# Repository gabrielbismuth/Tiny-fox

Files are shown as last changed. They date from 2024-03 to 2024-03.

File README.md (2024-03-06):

# Tiny-fox
Descripción del Proyecto Este repositorio contiene los archivos de diseño de una placa de circuito impreso (PCB) basada en el ESP32 Pico D4. La PCB ha sido diseñada con el objetivo de proporcionar una plataforma flexible y de código abierto para proyectos de IoT, desarrollo de productos y prototipado rápido.

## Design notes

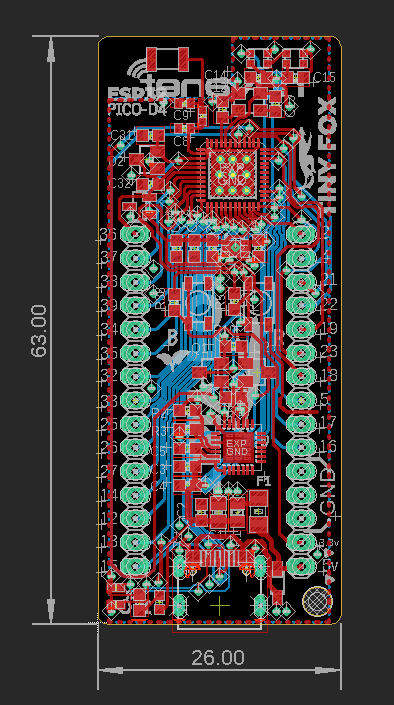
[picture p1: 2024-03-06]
tiny fox.png

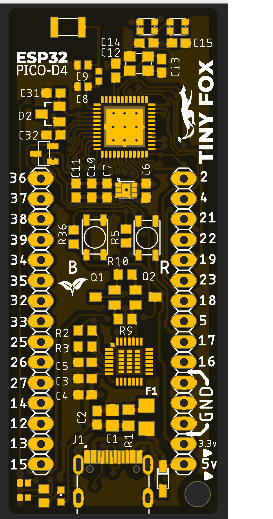
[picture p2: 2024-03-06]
tiny fox render.png

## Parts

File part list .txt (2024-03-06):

Partlist

Exported from tiny fox predatronics.sch at 05/03/2024 07:37 p. m.

EAGLE Version 9.5.2 Copyright (c) 1988-2019 Autodesk, Inc.

Assembly variant: 

Part     Value          Device                 Package            Library                 Sheet

C1       10uf           C-USC0805              C0805              rcl                     1
C2       0.1uf          C-USC0603              C0603              rcl                     1
C3       0.1uf          C-USC0603              C0603              rcl                     1
C4       1uf            C-USC0603              C0603              rcl                     1
C5       1uf            C-USC0603              C0603              rcl                     1
C6       1uf            C-USC0603              C0603              rcl                     1
C7       1uf            C-USC0603              C0603              rcl                     1
C8       1.5pf          C-USC0402              C0402              rcl                     1
C9       1.2pf          C-USC0402              C0402              rcl                     1
C10      0.1uf          C-USC0603              C0603              rcl                     1
C11      1uf            C-USC0603              C0603              rcl                     1
C12      18pf           C-USC0603              C0603              rcl                     1
C13      18pf           C-USC0603              C0603              rcl                     1
C14      0.1uf          C-USC0603              C0603              rcl                     1
C15      0.1uf          C-USC0603              C0603              rcl                     1
C31      0.1uf          C-USC0603              C0603              rcl                     1
C32      680pf          C-USC0603              C0603              rcl                     1
D2       BAS40-04       BAS40-04               SOT23              diode                   1
F1       6V/0.75A       PPTC_THREE-QUARTER-AMP 1206               SparkFun-Fuses          1
IC1      CP2102         CP2102                 MLP28              silabs                  1
J1       TYPE-C-31-M-12 TYPE-C-31-M-12         HRO_TYPE-C-31-M-12 TYPE-C-31-M-12          1
JP1                     PINHD-1X15             1X15               pinhead                 1
JP2                     PINHD-1X15             1X15               pinhead                 1
LED1                    LEDCHIPLED_0603        CHIPLED_0603       adafruit                1
Q1       MUN2211T1      MUN2211T1              SC59-BEC           transistor-npn          1
Q2       MUN2211T1      MUN2211T1              SC59-BEC           transistor-npn          1
R1       FB             R-US_R0805             R0805              audio amplifier example 1
R2       33R            R-US_R0603             R0603              resistor                1
R3       33R            R-US_R0603             R0603              resistor                1
R4       1k             R-US_R0603             R0603              resistor                1
R5       10k            R-US_R0603             R0603              adafruit                1
R6       5.1k           R-US_R0402             R0402              rcl                     1
R7       5.1k           R-US_R0402             R0402              rcl                     1
R9       10k            R-US_R0603             R0603              resistor                1
R10      10k            R-US_R0603             R0603              resistor                1
R36      10k            R-US_R0603             R0603              adafruit                1
U$1      ESP32-PICO-D4  ESP32-PICO-D4          QFN48              esp32-pico-d4           1
U$2      WS2812B-2020   WS2812B-2020           2020               ws2812b-2020            1
U$3      NCP705         NCP705                 WDFN6              NCP705                  1
U$4      6.1nH          INDUCTOR_0402_M        RESC0402_M         Nordic_nRF              1
U$5      CHIP-ANTHENA   CHIP-ANTHENA           ANTHENFOOT         NN01-110                1
U$6      ECX-32         ECX-32                 EXC-32             cristal                 1
U$7      WS2812B-2020   WS2812B-2020           2020               ws2812b-2020            1
U$10     RB160MM-50TF   RB160MM-50TF           SOD-123FL          RB160MM-50TF            1
U$21     TMP23X-Q1      TMP23X-Q1              SOT-23             TMP23x-Q1               1
U$22     XUNPU          XUNPU                  TS-1089S           TS-1089S-02526          1
U$23     XUNPU          XUNPU                  TS-1089S           TS-1089S-02526          1

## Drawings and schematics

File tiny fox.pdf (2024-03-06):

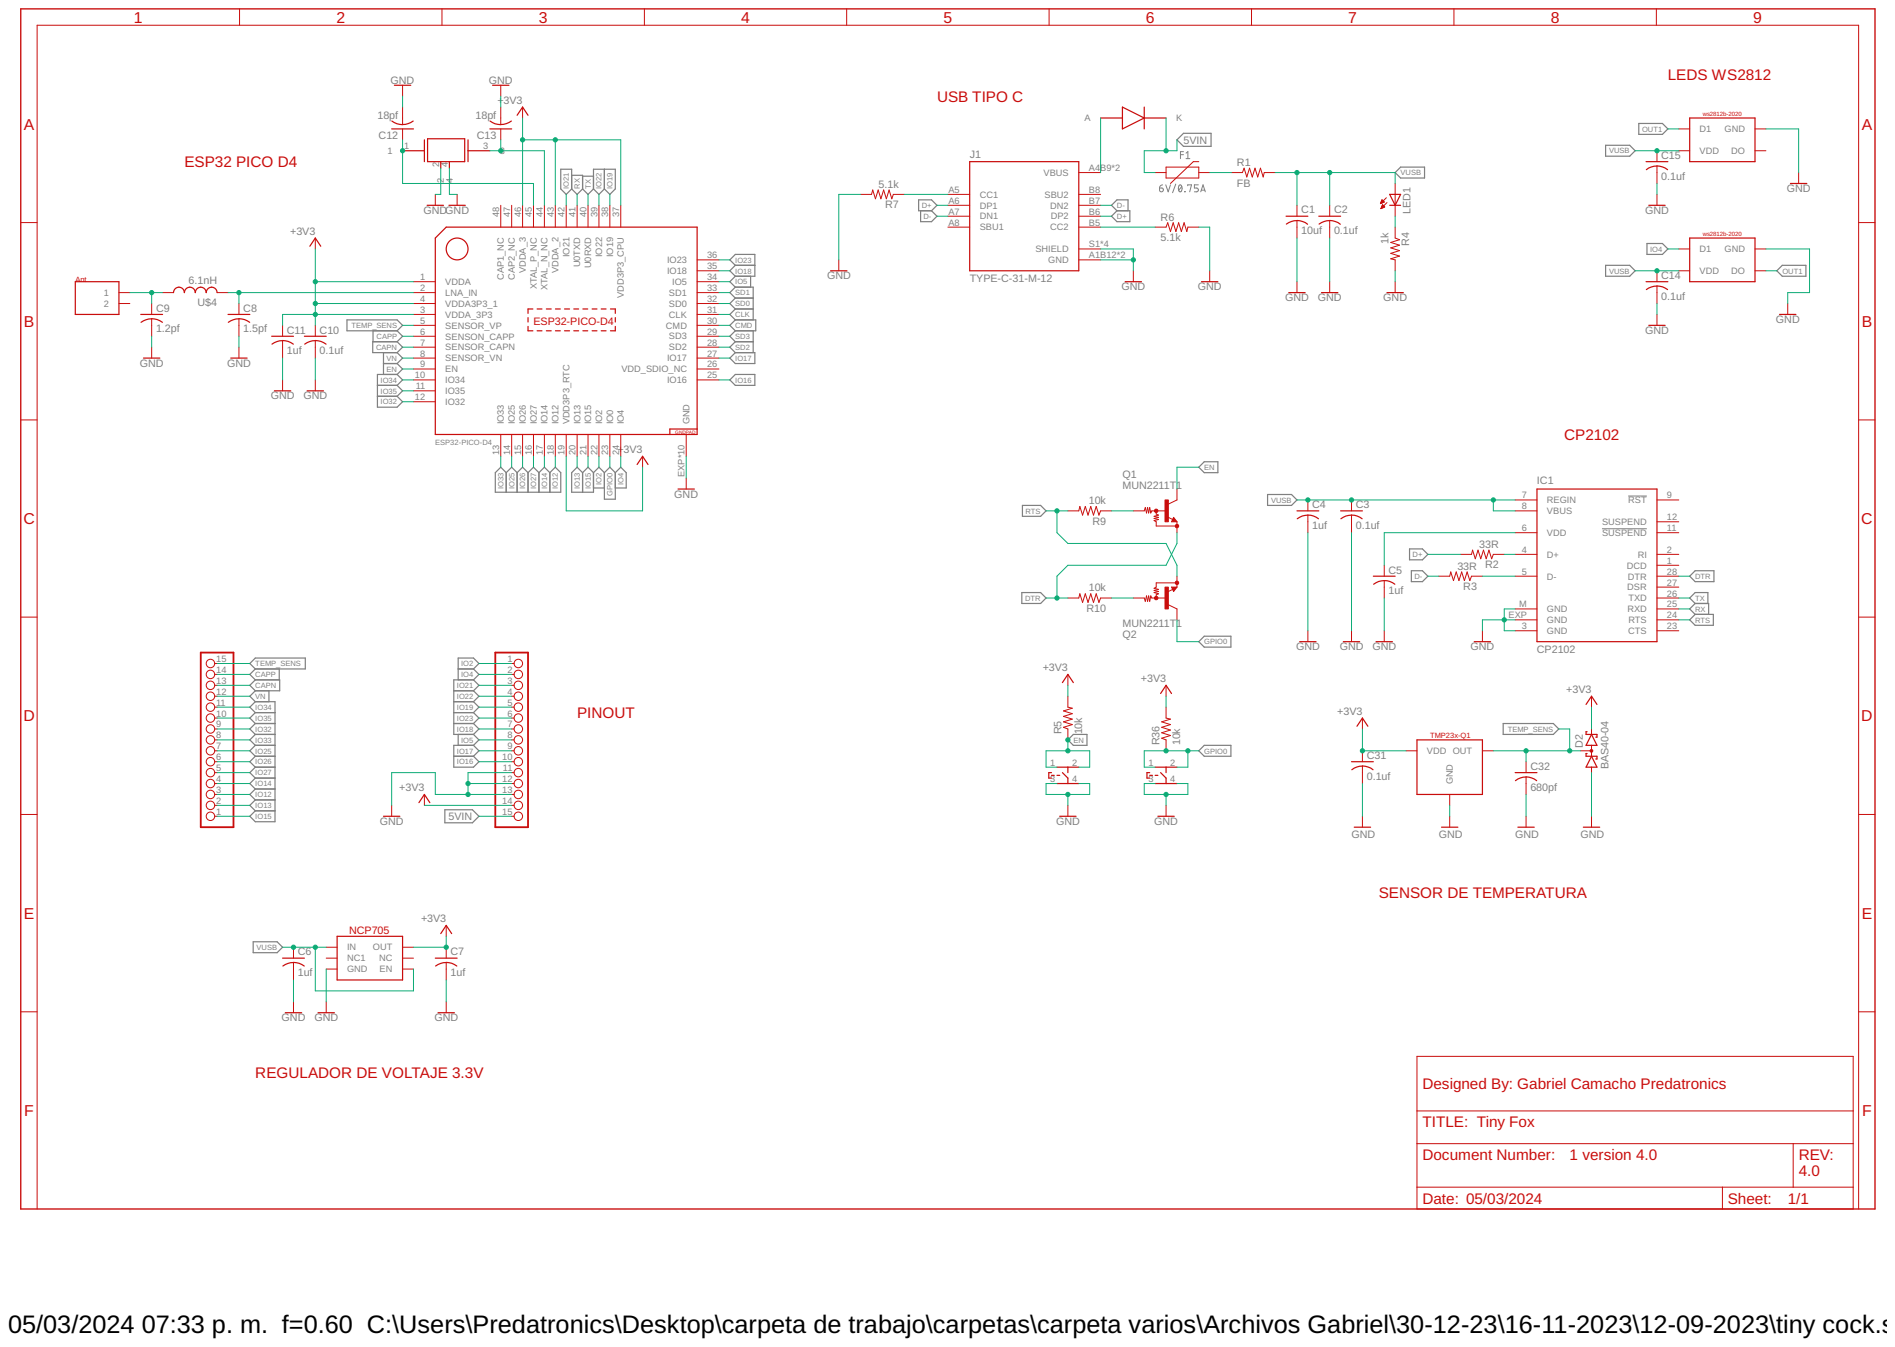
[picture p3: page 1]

Designed By: Gabriel Camacho Predatronics | 4.0

Tiny Fox 05/03/2024 Date: Sheet: 1/1 1 version 4.0 | REV: TITLE: Document Number:

05/03/2024 07:33 p. m. f=0.60 C:\Users\Predatronics\Desktop\carpeta de trabajo\carpetas\carpeta varios\Archivos Gabriel\30-12-23\16-11-2023\12-09-2023\tiny cock.sch (Sheet: 1/1)

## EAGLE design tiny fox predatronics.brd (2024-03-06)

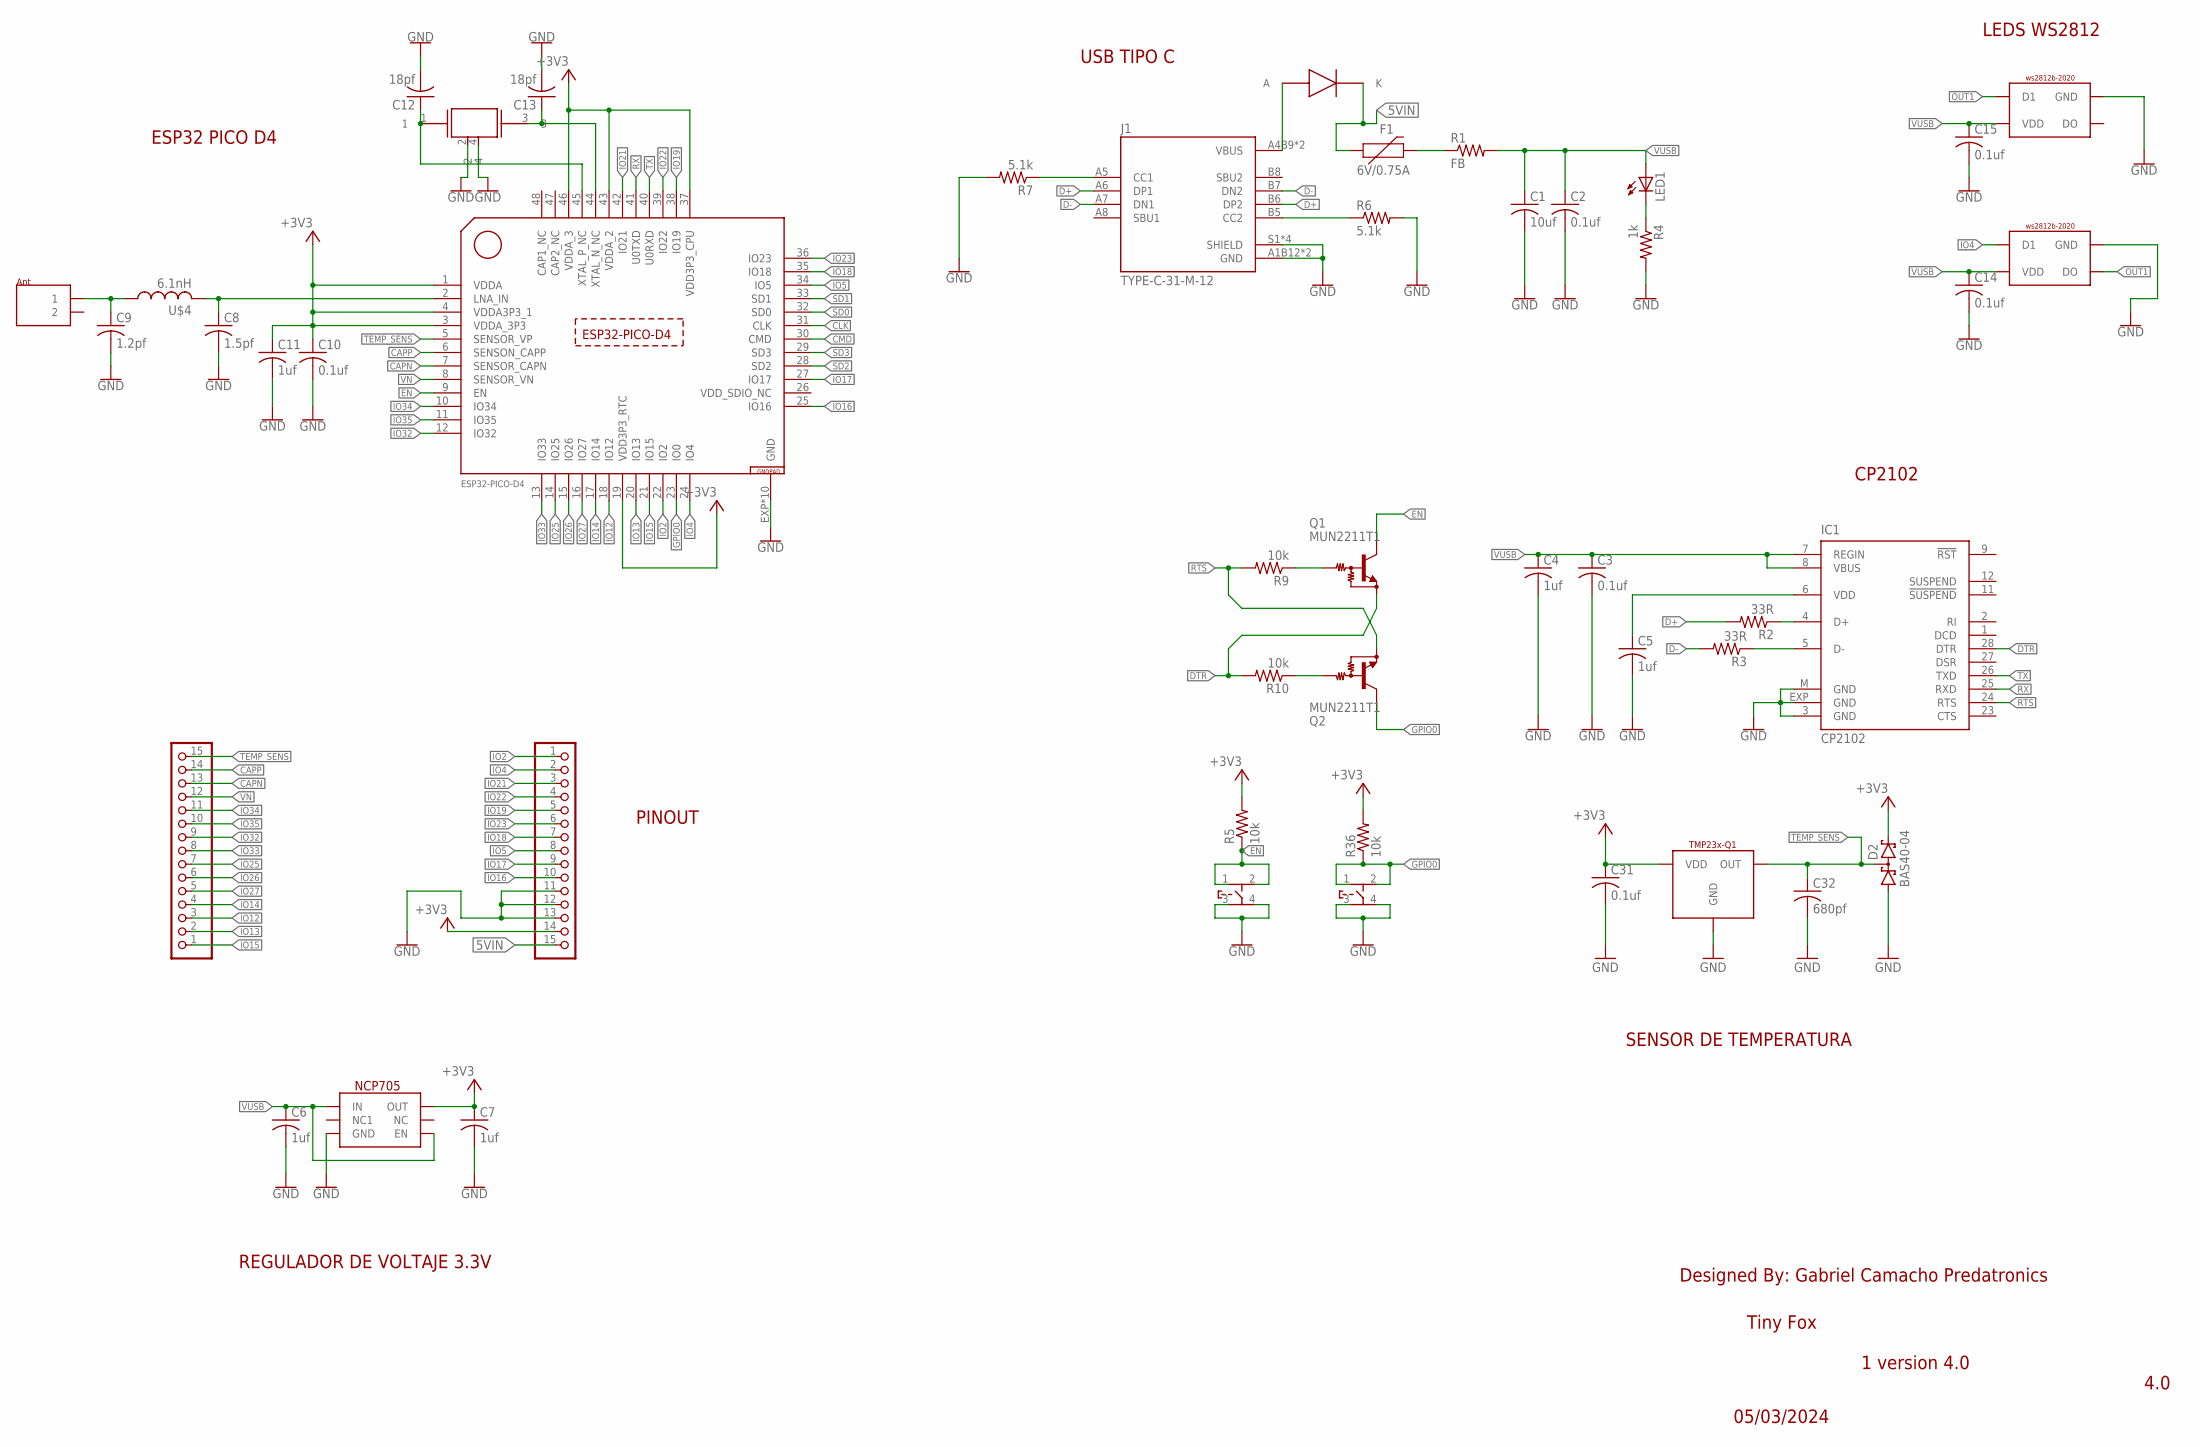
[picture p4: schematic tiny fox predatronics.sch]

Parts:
C1: 10uf; C0805
C2, C3, C10, C14, C15, C31: 0.1uf; C0603
C4, C5, C6, C7, C11: 1uf; C0603
C8: 1.5pf; C0402
C9: 1.2pf; C0402
C12, C13: 18pf; C0603
C32: 680pf; C0603
D2: BAS40-04; SOT23
F1: 6V/0.75A; 1206
IC1: CP2102; MLP28
J1: TYPE-C-31-M-12; HRO_TYPE-C-31-M-12
JP1, JP2: PINHD-1X15; 1X15
LED1: LEDCHIPLED_0603; CHIPLED_0603
Q1, Q2: MUN2211T1; SC59-BEC
R1: FB; R0805
R2, R3: 33R; R0603
R4: 1k; R0603
R5, R9, R10, R36: 10k; R0603
R6, R7: 5.1k; R0402
U$1: ESP32-PICO-D4; QFN48
U$2, U$7: WS2812B-2020; 2020
U$3: NCP705; WDFN6
U$4: 6.1nH; RESC0402_M
U$5: CHIP-ANTHENA; ANTHENFOOT
U$6: ECX-32; EXC-32
U$10: RB160MM-50TF; SOD-123FL
U$21: TMP23X-Q1; SOT-23
U$22, U$23: XUNPU; TS-1089S

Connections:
5VIN: F1.1, JP2.15, U$10.K
+3V3: C7.1, C10.1, C11.1, C31.1, D2.2 (C2), JP2.14, R5.2, R36.2, U$1.1 (VDDA), U$1.3 (VDDA_3P3), U$1.4 (VDDA3P3_1), U$1.19 (VDD3P3_RTC), U$1.37 (VDD3P3_CPU), U$1.43 (VDDA_2), U$1.46 (VDDA_3), U$3.OUT, U$21.VDD
CAPN: JP1.13, U$1.7 (SENSOR_CAPN)
CAPP: JP1.14, U$1.6 (SENSON_CAPP)
CLK: U$1.31 (CLK)
CMD: U$1.30 (CMD)
D+: J1.A6 (DP1), J1.B6 (DP2), R2.2
D-: J1.A7 (DN1), J1.B7 (DN2), R3.2
DTR: IC1.28 (DTR), Q1.E, R10.2
EN: Q1.C, R5.1, U$1.9 (EN), U$22.1, U$22.2
GND: C1.2, C2.2, C3.2, C4.2, C5.2, C6.2, C7.2, C8.2, C9.2, C10.2, C11.2, C12.2, C13.2, C14.2, C15.2, C31.2, C32.2, D2.1 (A1), IC1.3 (GND), IC1.EXP (GND), IC1.M (GND), J1.A1B12 (GND), J1.B1A12 (GND), J1.S1 (SHIELD), J1.S2 (SHIELD), J1.S3 (SHIELD), J1.S4 (SHIELD), JP2.11, JP2.12, JP2.13, R4.2, R6.2, R7.2, U$1.EXP (GND), U$1.P$1 (GND), U$1.P$2 (GND), U$1.P$3 (GND), U$1.P$4 (GND), U$1.P$5 (GND), U$1.P$6 (GND), U$1.P$7 (GND), U$1.P$8 (GND), U$1.P$9 (GND), U$2.GND, U$3.GND, U$3.P$7 (GND), U$3.P$8 (GND), U$6.2, U$6.4, U$7.GND, U$21.GND, U$22.3, U$22.4, U$23.3, U$23.4
GPIO0: Q2.C, R36.1, U$1.23 (IO0), U$23.1, U$23.2
IO2: JP2.1, U$1.22 (IO2)
IO4: JP2.2, U$1.24 (IO4), U$2.D1
IO5: JP2.8, U$1.34 (IO5)
IO12: JP1.3, U$1.18 (IO12)
IO13: JP1.2, U$1.20 (IO13)
IO14: JP1.4, U$1.17 (IO14)
IO15: JP1.1, U$1.21 (IO15)
IO16: JP2.10, U$1.25 (IO16)
IO17: JP2.9, U$1.27 (IO17)
IO18: JP2.7, U$1.35 (IO18)
IO19: JP2.5, U$1.38 (IO19)
IO21: JP2.3, U$1.42 (IO21)
IO22: JP2.4, U$1.39 (IO22)
IO23: JP2.6, U$1.36 (IO23)
IO25: JP1.7, U$1.14 (IO25)
IO26: JP1.6, U$1.15 (IO26)
IO27: JP1.5, U$1.16 (IO27)
IO32: JP1.9, U$1.12 (IO32)
IO33: JP1.8, U$1.13 (IO33)
IO34: JP1.11, U$1.10 (IO34)
IO35: JP1.10, U$1.11 (IO35)
unnamed: J1.A4B9 (VBUS), J1.B4A9 (VBUS), U$10.A
unnamed: J1.B5 (CC2), R6.1
unnamed: IC1.4 (D+), R2.1
unnamed: IC1.5 (D-), R3.1
unnamed: C5.1, IC1.6 (VDD)
unnamed: LED1.C, R4.1
unnamed: C9.1, U$4.1, U$5.1
unnamed: C8.1, U$1.2 (LNA_IN), U$4.2
unnamed: C13.1, U$1.44 (XTAL_N_NC), U$6.3
unnamed: Q1.B, R9.1
unnamed: Q2.B, R10.1
unnamed: C12.1, U$1.45 (XTAL_P_NC), U$6.1
unnamed: J1.A5 (CC1), R7.1
unnamed: F1.2, R1.1
OUT1: U$2.DO, U$7.D1
RTS: IC1.24 (RTS), Q2.E, R9.2
RX: IC1.25 (RXD), U$1.41 (U0TXD)
SD0: U$1.32 (SD0)
SD1: U$1.33 (SD1)
SD2: U$1.28 (SD2)
SD3: U$1.29 (SD3)
TEMP_SENS: C32.1, D2.3 (C1A2), JP1.15, U$1.5 (SENSOR_VP), U$21.VOUT (OUT)
TX: IC1.26 (TXD), U$1.40 (U0RXD)
VDD_SDIO_NC: U$1.26 (VDD_SDIO_NC)
VN: JP1.12, U$1.8 (SENSOR_VN)
VUSB: C1.1, C2.1, C3.1, C4.1, C6.1, C14.1, C15.1, IC1.7 (REGIN), IC1.8 (VBUS), LED1.A, R1.2, U$2.VDD, U$3.EN, U$3.IN, U$7.VDD

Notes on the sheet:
Tiny Fox
05/03/2024
Designed By: Gabriel Camacho Predatronics
4.0
1 version 4.0
ESP32 PICO D4
USB TIPO C
LEDS WS2812
CP2102
SENSOR DE TEMPERATURA
REGULADOR DE VOLTAJE 3.3V
PINOUT

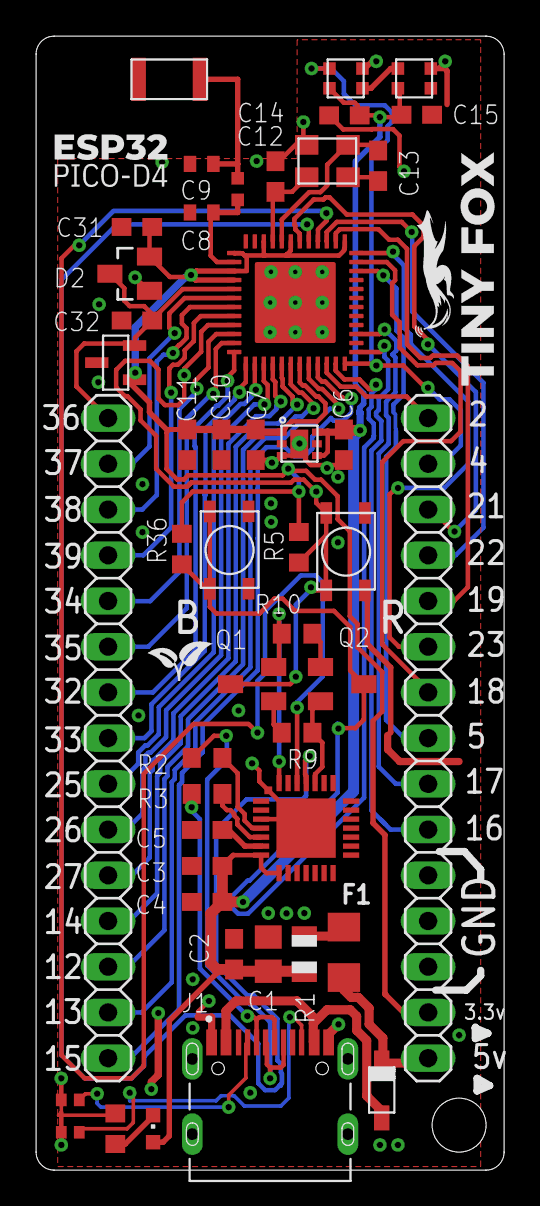
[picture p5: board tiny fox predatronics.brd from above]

Board: 2 copper layers, 26.0 x 63.0 mm, 47 parts (0 on the bottom side), 52 nets.

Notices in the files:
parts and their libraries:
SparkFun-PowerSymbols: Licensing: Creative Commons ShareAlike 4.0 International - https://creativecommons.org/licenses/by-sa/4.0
